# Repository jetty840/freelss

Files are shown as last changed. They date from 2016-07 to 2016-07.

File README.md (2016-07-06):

#FreeLSS

FreeLSS is a laser scanning program for the Raspberry Pi. It allows a Raspberry Pi to function as the core to a complete turn table laser scanning system.

###THIS FORK

This fork adds Neopixel ring support to freelss.  It includes the circuit/board design for a small mainly SMD shield to handle Neopixels / lasers and steppers.

The advantage of the Neopixel ring is adjustable color and brightness for illumination of the object and reporting of the ip address at startup (useful in DHCP configs).

If you are not usng Neopixels, you can still use the board and omit a few components if you require a small form factor, or use a different board.

Additionally, custom PWM (White) lighting can be setup such that the model and lasers can have different ambient lighting.

###COMPILE

These instructions assume you are running the latest version of Raspbian.  Other distros will likely require changes.

First, update the firmware to the latest version and reboot.
```
$ sudo apt-get update
$ sudo apt-get upgrade
```

Install the dependencies that are managed by the package manager.
```
$ sudo apt-get install libpng-dev libjpeg-dev cmake vlc git-core gcc build-essential unzip sqlite3 libsqlite3-dev libmicrohttpd-dev libcurl4-openssl-dev libiw-dev libssl-dev
```

Download and install wiringPi
```
$ git clone git://git.drogon.net/wiringPi
$ cd wiringPi
$ ./build
$ cd ..
```

Disable the soundcard on the Pi (interferes with Neopixels):
Reference: http://www.instructables.com/id/Disable-the-Built-in-Sound-Card-of-Raspberry-Pi/
```
$ cd /etc/modprobe.d
$ sudo vi alsa-blacklist.conf
Add the following line:
  blacklist snd_bcm2835
Save
$ sudo reboot

After reboot:
$ aplay -l
  Should say "No soundcards found"

```

Download and install rpi_ws821x
Reference: https://learn.adafruit.com/neopixels-on-raspberry-pi/software
```
$ sudo apt-get install build-essential python-dev git scone swig
$ git clone https://github.com/jgarff/rpi_ws281x.git
$ cd rpi_ws281x
$ scons
$ sudo ./test
(Neopixels will go through color cycling, press CTRL-C when done)
$ cd ..
```

Download and build FreeLSS
```
$ git clone https://github.com/jetty840/freelss
$ cd freelss/src
$ make
```
###Running FreeLSS
FreeLSS must be ran as root (or another user with access to the hardware pins).  The interface for FreeLSS is web based and by default runs on port 80.  When running, access it by navigating to http://localhost/ from the Raspberry Pi itself. Or access it from another machine on the network by the Raspberry Pi's IP or hostname.  For Example: http://raspberrypi/

The following command starts FreeLSS.
```
$ sudo ./freelss
```

The following command automatically starts FreeLSS everytime the Raspberry Pi is powered on.
```
$ make startup
```

###Pin Configuraton
For FreeLSS running with the provided schematic/PCB in this fork, configuration for this board is as follows:
```
Right Laser Pin: 4
Left Laser Pin: 0
Laser On Value: 1
Motor Enable Pin: 5
Motor Step Pin: 2
Motor Step Delay: 5000
Motor Direction Pin: 3
Motor Response Delay: 2
Enable Lighting: Checked
Light Type: WS281x
Lighting Pin: 18
```

###Building the board
Populate R4/R6 OR D1/D2, depending on your laser diodes.  If it's 5V and can control it's own current, then populate R4/R6 with a zero ohm resistor.  Otherwise to get the correct voltage for the laser diode, D1/D2 can be used as a Diode drop, and the trace from the middle of the diode pair to +5V can be cut and used as 2 diode drops if required.  Alternative R4/R6 can be used to limit voltage/current less accurately.

For the PI header, decide if you want to use it as a shield (use a PI Stacking Header), or wire 0.1" pin headers if you wish to cable it out (verify pin 1 = pin 1 if you're using IDC headers and a cable).

Adafruit 12 LED Neopixel ring recommended (720ma).  Be careful of current here, the Pi needs to be able to handle it, or supply power using a different method.

2A Minimum 5V PSU required.

DISCLAIMER: By using this design and/or fork, you acknowledge that you do so entirely at your own risk and that you will not hold the author liable under any cicrumstances.

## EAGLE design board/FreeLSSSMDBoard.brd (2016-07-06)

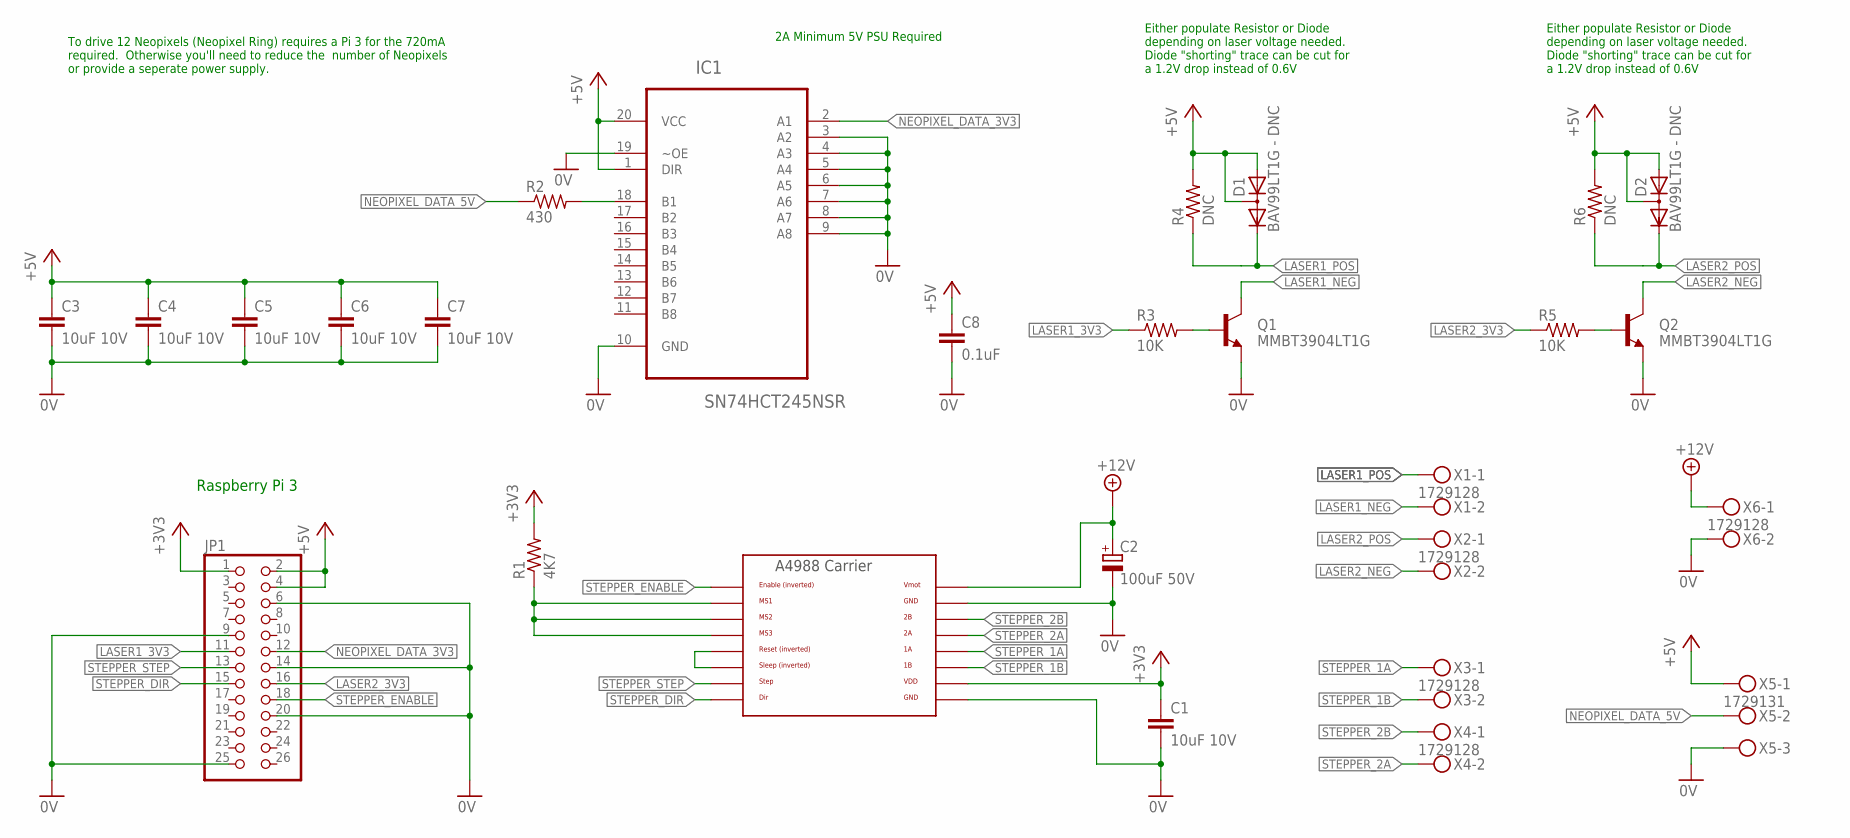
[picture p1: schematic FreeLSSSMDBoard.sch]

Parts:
C1, C3, C4, C5, C6, C7: 10uF 10V; C0603K
C2: 100uF 50V; E3,5-8
C8: 0.1uF; C0603K
D1, D2: BAV99LT1G - DNC; SOT23
IC1: SN74HCT245NSR; SOP-20
JP1: PINHD-2X13; 2X13
Q1, Q2: MMBT3904LT1G; SOT23-BEC
R1: 4K7; R0603
R2: 430; R0603
R3, R5: 10K; R0603
R4, R6: DNC; R0603
U$1: A4988BREAKOUT
X1, X2, X3, X4, X6: 1729128; MKDSN1,5/2-5,08
X5: 1729131; MKDSN1,5/3-5,08

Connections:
0V: C1.2, C2.-, C3.2, C4.2, C5.2, C6.2, C7.2, C8.2, IC1.3 (A2), IC1.4 (A3), IC1.5 (A4), IC1.6 (A5), IC1.7 (A6), IC1.8 (A7), IC1.9 (A8), IC1.10 (GND), IC1.19 (~OE), JP1.6, JP1.9, JP1.14, JP1.20, JP1.25, Q1.E, Q2.E, U$1.GND, U$1.GND@0 (GND), X5.3, X6.2
+3V3: C1.1, JP1.1, R1.2, U$1.VDD
+5V: C3.1, C4.1, C5.1, C6.1, C7.1, C8.1, D1.1 (A), D1.3 (AC), D2.1 (A), D2.3 (AC), IC1.1 (DIR), IC1.20 (VCC), JP1.2, JP1.4, R4.2, R6.2, X5.1
+12V: C2.+, U$1.VMOT, X6.1
LASER1_3V3: JP1.11, R3.1
LASER1_NEG: Q1.C, X1.2
LASER1_POS: D1.2 (C), R4.1, X1.1
LASER2_3V3: JP1.16, R5.1
LASER2_NEG: Q2.C, X2.2
LASER2_POS: D2.2 (C), R6.1, X2.1
unnamed: U$1.RST, U$1.SLP (SLEEP)
unnamed: R1.1, U$1.MS1, U$1.MS2, U$1.MS3
unnamed: IC1.18 (B1), R2.2
unnamed: Q1.B, R3.2
unnamed: Q2.B, R5.2
NEOPIXEL_DATA_3V3: IC1.2 (A1), JP1.12
NEOPIXEL_DATA_5V: R2.1, X5.2
STEPPER_1A: U$1.1A, X3.1
STEPPER_1B: U$1.1B, X3.2
STEPPER_2A: U$1.2A, X4.2
STEPPER_2B: U$1.2B, X4.1
STEPPER_DIR: JP1.15, U$1.DIR
STEPPER_ENABLE: JP1.18, U$1.EN
STEPPER_STEP: JP1.13, U$1.STEP

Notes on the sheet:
Raspberry Pi 3
Either populate Resistor or Diode depending on laser voltage needed. Diode "shorting" trace can be cut for a 1.2V drop instead of 0.6V
To drive 12 Neopixels (Neopixel Ring) requires a Pi 3 for the 720mA required. Otherwise you'll need to reduce the number of Neopixels or provide a seperate power supply.
2A Minimum 5V PSU Required

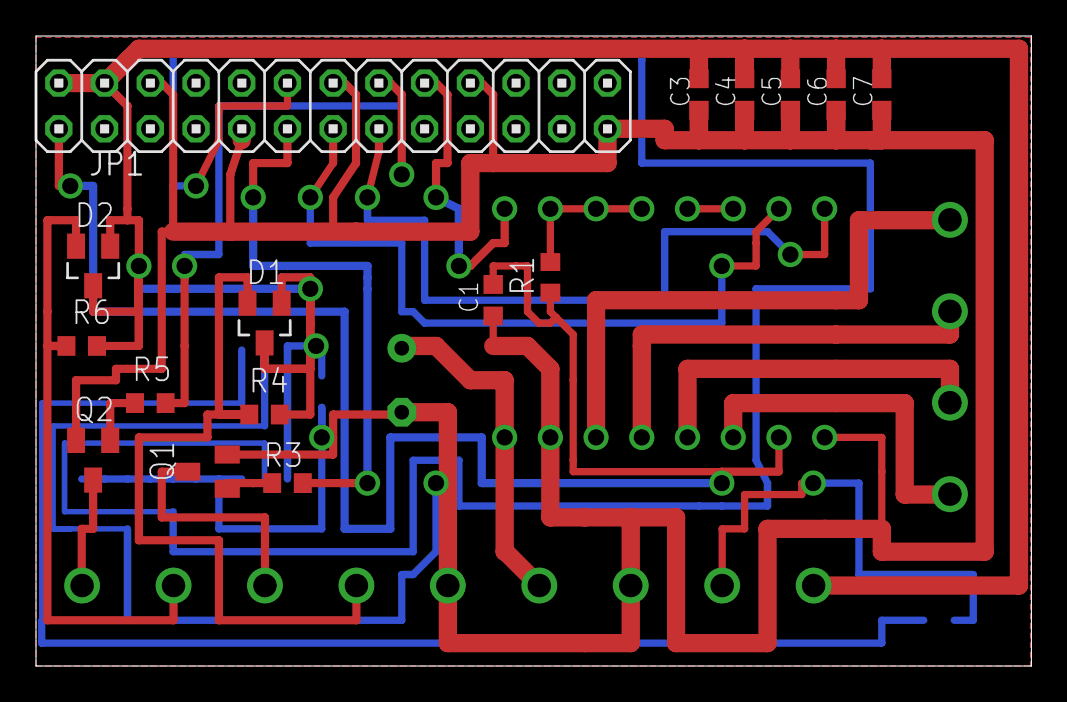
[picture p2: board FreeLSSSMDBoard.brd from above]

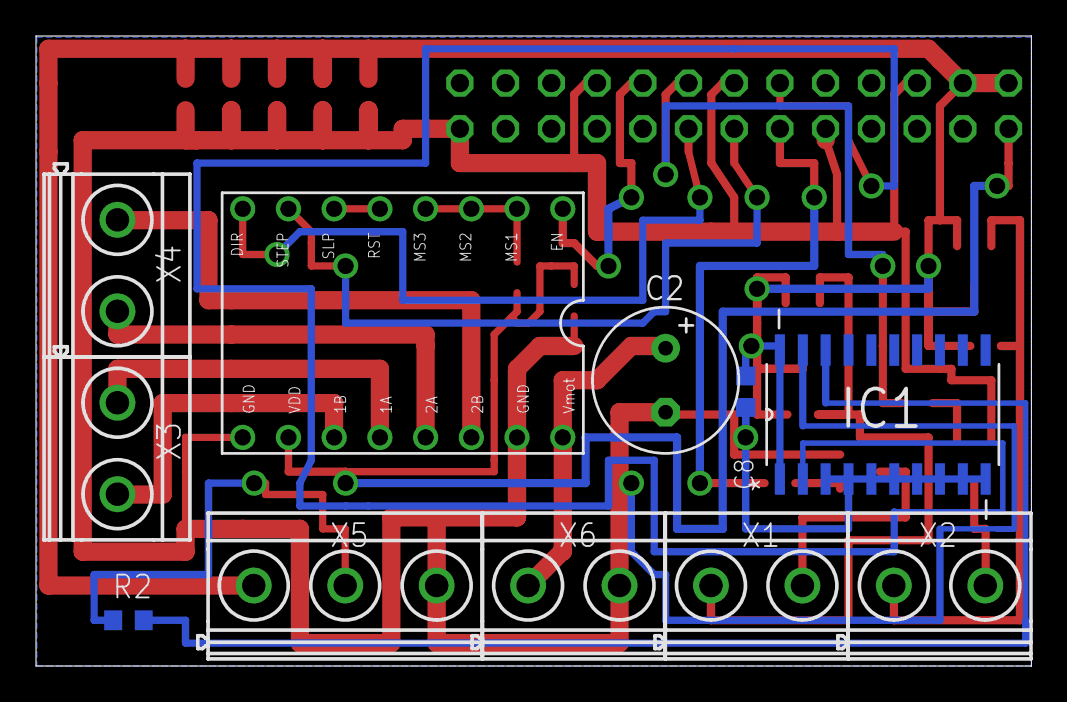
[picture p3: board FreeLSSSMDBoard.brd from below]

Board: 2 copper layers, 55.3 x 35.0 mm, 27 parts (11 on the bottom side), 24 nets.

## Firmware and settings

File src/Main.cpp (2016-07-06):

/*
 ****************************************************************************
 *  Copyright (c) 2014 Uriah Liggett <freelaserscanner@gmail.com>           *
 *	This file is part of FreeLSS.                                           *
 *                                                                          *
 *  FreeLSS is free software: you can redistribute it and/or modify         *
 *  it under the terms of the GNU General Public License as published by    *
 *  the Free Software Foundation, either version 3 of the License, or       *
 *  (at your option) any later version.                                     *
 *                                                                          *
 *  FreeLSS is distributed in the hope that it will be useful,              *
 *  but WITHOUT ANY WARRANTY; without even the implied warranty of          *
 *  MERCHANTABILITY or FITNESS FOR A PARTICULAR PURPOSE.  See the           *
 *  GNU General Public License for more details.                            *
 *                                                                          *
 *   You should have received a copy of the GNU General Public License      *
 *   along with FreeLSS.  If not, see <http://www.gnu.org/licenses/>.       *
 ****************************************************************************
*/

#include "Main.h"
#include "Camera.h"
#include "Scanner.h"
#include "A4988TurnTable.h"
#include "RelayLaser.h"
#include "PresetManager.h"
#include "HttpServer.h"
#include "PresetManager.h"
#include "PropertyReaderWriter.h"
#include "Setup.h"
#include "UpdateManager.h"
#include "Lighting.h"
#include "WifiConfig.h"
#include <curl/curl.h>
#include <algorithm>

static bool SortRecordByRow(const freelss::DataPoint& a, const freelss::DataPoint& b)
{
	return a.pixel.y < b.pixel.y;
}

std::string GetPropertiesFile()
{
	// Get the users home directory
	char * home = getenv("HOME");
	if (home == NULL)
	{
		std::cerr << "Could not detect the user's home directory";
		return "";
	}

	return home + std::string("/.freelss.properties");
}

/** Initializes and destroys libcurl */
struct InitCurl
{
	InitCurl()
	{
		curl_global_init(CURL_GLOBAL_ALL);
	}

	~InitCurl()
	{
		curl_global_cleanup();
	}
};

/** Initializes and destroys the singletons */
struct InitSingletons
{
	InitSingletons()
	{
		freelss::PresetManager::get();
		freelss::A4988TurnTable::initialize();
		freelss::RelayLaser::initialize();
		freelss::UpdateManager::get();
		freelss::Setup::get();
		freelss::Lighting::get();
		freelss::WifiConfig::get();
		freelss::HttpServer::get();
	}

	~InitSingletons()
	{
		freelss::HttpServer::release();
		freelss::Laser::release();
		freelss::Camera::release();
		freelss::TurnTable::release();
		freelss::UpdateManager::release();
		freelss::PresetManager::release();
		freelss::Lighting::release();
		freelss::WifiConfig::release();
		freelss::Setup::release();
	}
};

/** Initializes and destroys the Raspberry Pi subsystem */
struct InitBcmHost
{
	InitBcmHost()
	{
		bcm_host_init();
	}

	~InitBcmHost()
	{
		bcm_host_deinit();
	}
};

int main(int argc, char **argv)
{
	int retVal = 0;

	pid_t pid = fork();
	if (pid < 0)
	{
		std::cerr << "Error forking process!!!" << std::endl;
		return 1;
	}
	else if (pid != 0)
	{
		return 0;
	}

	// Initialize the Raspberry Pi hardware
	InitBcmHost bcmHost;

	try
	{
		// Setup wiring pi
		wiringPiSetup();

		// Initialize Curl
		InitCurl curl();

		// Load the properties
		freelss::LoadProperties();

		// Initialize the singletons
		InitSingletons singletons;

		freelss::WifiConfig::get()->displayNetworkIpAddress();

		int port = freelss::Setup::get()->httpPort;

		std::cout << "Running on port " << port << "..." << std::endl;
		freelss::HttpServer::get()->start(port);

		while (true)
		{
			freelss::Thread::usleep(500000);  // Sleep 500ms
		}
	}
	catch (freelss::Exception& ex)
	{
		std::cerr << "Exception: " << ex << std::endl;
		retVal = -1;
	}
	catch (std::exception& ex)
	{
		std::cerr << "Exception: " << ex.what() << std::endl;
		retVal = -1;
	}
	catch (...)
	{
		std::cerr << "Unknown Exception Occurred" << std::endl;
		retVal = -1;
	}

	return retVal;
}

namespace freelss
{

const std::string SCAN_OUTPUT_DIR = "/scans";
const std::string DEBUG_OUTPUT_DIR = "/debug";
const std::string PROPERTIES_FILE = GetPropertiesFile();

time_t ScanResult::getScanDate() const
{
	if (files.empty())
	{
		return 0;
	}

	return files.front().creationTime;
}

bool DataPoint::readNextFrame(std::vector<DataPoint>& out, const std::vector<DataPoint>& results, size_t & resultIndex)
{
	out.clear();

	if (resultIndex >= results.size() || results.empty())
	{
		return false;
	}

	int pseudoStep = results[resultIndex].pseudoFrame;
	while (pseudoStep == results[resultIndex].pseudoFrame && resultIndex < results.size())
	{
		out.push_back(results[resultIndex]);
		resultIndex++;
	}

	return true;
}

bool DataPoint::readNextFrame(const std::vector<DataPoint>& results, size_t & resultIndex)
{
	if (resultIndex >= results.size() || results.empty())
	{
		return false;
	}

	int pseudoStep = results[resultIndex].pseudoFrame;
	while (pseudoStep == results[resultIndex].pseudoFrame && resultIndex < results.size())
	{
		resultIndex++;
	}

	return true;
}

void DataPoint::computeAverage(const std::vector<DataPoint>& bin, DataPoint& out)
{
	out = bin.front();

	real32 invSize = 1.0f / bin.size();

	real32 rotation = 0;
	real32 pixelLocationX = 0;
	real32 pixelLocationY = 0;
	real32 ptX = 0;
	real32 ptY = 0;
	real32 ptZ = 0;
	real32 ptR = 0;
	real32 ptG = 0;
	real32 ptB = 0;

	for (size_t iBin = 0; iBin < bin.size(); iBin++)
	{
		const DataPoint& br = bin[iBin];

		rotation += invSize * br.rotation;
		pixelLocationX += invSize * br.pixel.x;
		pixelLocationY += invSize * br.pixel.y;
		ptX += invSize * br.point.x;
		ptY += invSize * br.point.y;
		ptZ += invSize * br.point.z;
		ptR += invSize * br.point.r;
		ptG += invSize * br.point.g;
		ptB += invSize * br.point.b;
	}

	out.rotation = rotation;
	out.pixel.x = pixelLocationX;  // TODO: We should probably round these values
	out.pixel.y = pixelLocationY;
	out.point.x = ptX;
	out.point.y = ptY;
	out.point.z = ptZ;
	out.point.r = ptR;
	out.point.g = ptG;
	out.point.b = ptB;
}

void DataPoint::lowpassFilter(std::vector<DataPoint>& output, std::vector<DataPoint>& frame, unsigned maxNumRows, unsigned numRowBins)
{
	// Sanity check
	if (frame.empty())
	{
		return;
	}

	// No binning can occur, so copy
	if (numRowBins >= maxNumRows)
	{
		output.insert(output.end(), frame.begin(), frame.end());
		return;
	}

	// Sort by image row
	std::sort(frame.begin(), frame.end(), SortRecordByRow);

	unsigned binSize = maxNumRows / numRowBins;

	// Holds the current contents of the bin
	std::vector<DataPoint> bin;
	unsigned nextBinY = frame.front().pixel.y + binSize;

	// unsigned bin = frame.front().pixel.y / numRowBins;
	for (size_t iFr = 0; iFr < frame.size(); iFr++)
	{
		DataPoint& record = frame[iFr];

		if (record.pixel.y < nextBinY)
		{
			bin.push_back(record);
		}
		else
		{
			// Average the bin results and add it to the output
			if (!bin.empty())
			{
				DataPoint out;
				computeAverage(bin, out);

				output.push_back(out);
				bin.clear();
			}

			nextBinY = record.pixel.y + binSize;
			bin.push_back(record);
		}
	}

	// Process any results still left in the bin
	if (!bin.empty())
	{
		DataPoint out;
		computeAverage(bin, out);

		output.push_back(out);
		bin.clear();
	}
}


void LoadProperties()
{
	PropertyReaderWriter reader;

	std::vector<Property> properties;

	// Read the presets from the file
	if (access(PROPERTIES_FILE.c_str(), F_OK) != -1)
	{
		properties = reader.readProperties(PROPERTIES_FILE);
	}

	PresetManager * presetMgr = PresetManager::get();

	// Read the presets
	presetMgr->decodeProperties(properties);

	// Create the default Preset object if there are no presets
	if (presetMgr->getPresets().empty())
	{
		Preset defaultPreset;
		defaultPreset.name = "Default";

		defaultPreset.id = presetMgr->addPreset(defaultPreset);
		presetMgr->setActivePreset(defaultPreset.id);
	}

	// Load the hardware setup information
	Setup::get()->decodeProperties(properties);
}

void SaveProperties()
{
	// Encode the info as Property objects
	std::vector<Property> properties;
	PresetManager::get()->encodeProperties(properties);
	Setup::get()->encodeProperties(properties);

	PropertyReaderWriter writer;
	writer.writeProperties(properties, PROPERTIES_FILE);
}

real ConvertUnitOfLength(real value, UnitOfLength srcUnits, UnitOfLength dstUnits)
{
	// Shortcut
	if (srcUnits == dstUnits)
	{
		return value;
	}

	//
	// Convert to millimeters
	//
	real mmValue;
	if (srcUnits == UL_MILLIMETERS)
	{
		mmValue = value;
	}
	else if (srcUnits == UL_CENTIMETERS)
	{
		mmValue = value * 10.0;
	}
	else if (srcUnits == UL_INCHES )
	{
		mmValue = value * 25.4;
	}
	else
	{
		throw Exception("Unsupported Unit of Length");
	}

	//
	// Convert to destination units
	//
	real out;
	if (dstUnits == UL_MILLIMETERS)
	{
		out = mmValue;
	}
	else if (dstUnits == UL_CENTIMETERS)
	{
		out = mmValue / 10.0;
	}
	else if (dstUnits == UL_INCHES)
	{
		out = mmValue / 25.4;
	}
	else
	{
		throw Exception("Unsupported Unit of Length");
	}

	return out;
}

double GetTimeInSeconds()
{
	struct timeval tv;
	if (gettimeofday(&tv, NULL) != 0)
	{
		std::cerr << "Error calling gettimeofday()" << std::endl;
	}

	double sec = tv.tv_sec;

	if (tv.tv_usec != 0)
	{
		sec += tv.tv_usec / 1000000.0;  // US to SEC
	}

	return sec;
}

int GetFreeSpaceMb()
{
	int freeSpaceMb = 0;
	struct statvfs fileSystemInfo;
	if (statvfs(SCAN_OUTPUT_DIR.c_str(), &fileSystemInfo) == 0)
	{
		real freeSpaceBytes = (real)fileSystemInfo.f_bsize * (real)fileSystemInfo.f_bfree;
		freeSpaceMb = (int)(freeSpaceBytes / 1024.0f / 1024.0f);
	}

	return freeSpaceMb;
}

std::string ToString(UnitOfLength unit)
{
	std::string out;

	switch(unit)
	{
	case UL_MILLIMETERS:
		out = "mm";
		break;

	case UL_CENTIMETERS:
		out = "cm";
		break;

	case UL_INCHES:
		out = "in";
		break;

	default:
		throw Exception("Unsupported unit of measure");
	}

	return out;
}

std::string ToHexString(unsigned char * data, size_t dataLength)
{
	std::stringstream sstr;
	for (size_t iDat = 0; iDat < dataLength; iDat++)
	{
		sstr << std::setbase(16) << (unsigned) data[iDat];
	}

	return sstr.str();
}

std::string ToString(real value)
{
	std::stringstream sstr;
	sstr << value;

	return sstr.str();
}

std::string ToString(int value)
{
	std::stringstream sstr;
	sstr << value;

	return sstr.str();
}

std::string ToString(bool value)
{
	return value ? "1" : "0";
}

std::string ToString(uint32_t value)
{
	std::stringstream sstr;
	sstr << std::setfill('0') << std::setw(6) << std::hex << value;

	return sstr.str();
}

real ToReal(const std::string& str)
{
	return atof(str.c_str());
}

int ToInt(const std::string& str)
{
	return atoi(str.c_str());
}

uint32_t ToUInt32(const std::string& str)
{
	return (uint32_t)strtoul(str.c_str(), NULL, 16);
}

bool ToBool(const std::string& str)
{
	return str == "1" || str == "true" || str == "on";
}

bool EndsWith(const std::string& str, const std::string& ending)
{
	if (str.length() >= ending.length())
	{
		return (0 == str.compare (str.length() - ending.length(), ending.length(), ending));
	}

	return false;
}

void HtmlEncode(std::string& str)
{
    std::string buffer;
    buffer.reserve(str.size());
    for(size_t iPos = 0; iPos != str.size(); ++iPos)
    {
        switch(str[iPos])
        {
            case '\"': buffer.append("&quot;");      break;
            case '\'': buffer.append("&apos;");      break;
            case '<':  buffer.append("&lt;");        break;
            case '>':  buffer.append("&gt;");        break;
            case '.':  buffer.append("&#46;");       break;
            case '=':  buffer.append("&#61;");       break;
            default:   buffer.append(&str[iPos], 1); break;
        }
    }

    str.swap(buffer);
}

void ExitProgram()
{
	//G_running = false;
}

} // ns scanner

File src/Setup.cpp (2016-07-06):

/*
 ****************************************************************************
 *  Copyright (c) 2015 Uriah Liggett <freelaserscanner@gmail.com>           *
 *	This file is part of FreeLSS.                                           *
 *                                                                          *
 *  FreeLSS is free software: you can redistribute it and/or modify         *
 *  it under the terms of the GNU General Public License as published by    *
 *  the Free Software Foundation, either version 3 of the License, or       *
 *  (at your option) any later version.                                     *
 *                                                                          *
 *  FreeLSS is distributed in the hope that it will be useful,              *
 *  but WITHOUT ANY WARRANTY; without even the implied warranty of          *
 *  MERCHANTABILITY or FITNESS FOR A PARTICULAR PURPOSE.  See the           *
 *  GNU General Public License for more details.                            *
 *                                                                          *
 *   You should have received a copy of the GNU General Public License      *
 *   along with FreeLSS.  If not, see <http://www.gnu.org/licenses/>.       *
 ****************************************************************************
*/
#include "Main.h"
#include "Setup.h"

namespace freelss
{

Setup * Setup::m_instance = NULL;

Setup * Setup::get()
{
	if (Setup::m_instance == NULL)
	{
		Setup::m_instance = new Setup();
	}

	return Setup::m_instance;
}

void Setup::release()
{
	delete Setup::m_instance;
	Setup::m_instance = NULL;
}

Setup::Setup() :
	cameraLocation(),
	leftLaserLocation(),
	rightLaserLocation(),
	rightLaserPin(5),
	leftLaserPin(4),
	motorEnablePin(0),
	motorStepPin(7),
	motorDirPin(1),
	motorDirPinValue(0),
	laserOnValue(1),
	stepsPerRevolution(3200),
	motorResponseDelay(2),
	motorStepDelay(5000),
	httpPort(80),
	serialNumber(""),
	unitOfLength(UL_INCHES),
	haveLaserPlaneNormals(false),
	enableLighting(false),
	lightingType(LT_PWM),
	lightingPin(3),
	lightingIlluminationRGB(0xFFFFFF),
	lightingLaserRGB(0x222222),
	lightingNetworkIndication(LN_OFF),
	lightingNetworkInterface("eth0"),
	enableAuthentication(false),
	passwordHash("")
{
	cameraLocation.x = 0;
	cameraLocation.y = 82.55;
	cameraLocation.z = 260.35;

	leftLaserLocation.x = -125.73;
	leftLaserLocation.y = 82.55;
	leftLaserLocation.z = 260.35;

	rightLaserLocation.x = 125.73;
	rightLaserLocation.y = 82.55;
	rightLaserLocation.z = 260.35;

	leftLaserPlaneNormal.x = 0;
	leftLaserPlaneNormal.y = 0;
	leftLaserPlaneNormal.z = 0;

	rightLaserPlaneNormal.x = 0;
	rightLaserPlaneNormal.y = 0;
	rightLaserPlaneNormal.z = 0;
}


void Setup::encodeProperties(std::vector<Property>& properties)
{
	properties.push_back(Property("setup.cameraLocation.x", ToString(cameraLocation.x)));
	properties.push_back(Property("setup.cameraLocation.y", ToString(cameraLocation.y)));
	properties.push_back(Property("setup.cameraLocation.z", ToString(cameraLocation.z)));

	properties.push_back(Property("setup.leftLaserLocation.x", ToString(leftLaserLocation.x)));
	properties.push_back(Property("setup.leftLaserLocation.y", ToString(leftLaserLocation.y)));
	properties.push_back(Property("setup.leftLaserLocation.z", ToString(leftLaserLocation.z)));

	properties.push_back(Property("setup.rightLaserLocation.x", ToString(rightLaserLocation.x)));
	properties.push_back(Property("setup.rightLaserLocation.y", ToString(rightLaserLocation.y)));
	properties.push_back(Property("setup.rightLaserLocation.z", ToString(rightLaserLocation.z)));

	properties.push_back(Property("setup.rightLaserPin", ToString(rightLaserPin)));
	properties.push_back(Property("setup.leftLaserPin", ToString(leftLaserPin)));
	properties.push_back(Property("setup.motorEnablePin", ToString(motorEnablePin)));
	properties.push_back(Property("setup.motorStepPin", ToString(motorStepPin)));
	properties.push_back(Property("setup.motorDirPin", ToString(motorDirPin)));
	properties.push_back(Property("setup.motorDirPinValue", ToString(motorDirPinValue)));
	properties.push_back(Property("setup.laserOnValue", ToString(laserOnValue)));
	properties.push_back(Property("setup.stepsPerRevolution", ToString(stepsPerRevolution)));
	properties.push_back(Property("setup.motorResponseDelay", ToString(motorResponseDelay)));
	properties.push_back(Property("setup.motorStepDelay", ToString(motorStepDelay)));
	properties.push_back(Property("setup.httpPort", ToString(httpPort)));
	properties.push_back(Property("setup.serialNumber", serialNumber));
	properties.push_back(Property("setup.unitOfLength", ToString((int)unitOfLength)));
	properties.push_back(Property("setup.haveLaserPlaneNormals", ToString(haveLaserPlaneNormals)));
	properties.push_back(Property("setup.enableLighting", ToString(enableLighting)));
	properties.push_back(Property("setup.lightingType", ToString((int)lightingType)));
	properties.push_back(Property("setup.lightingPin", ToString(lightingPin)));
	properties.push_back(Property("setup.lightingIlluminationRGB", ToString(lightingIlluminationRGB)));
	properties.push_back(Property("setup.lightingLaserRGB", ToString(lightingLaserRGB)));
	properties.push_back(Property("setup.lightingNetworkIndication", ToString((int)lightingNetworkIndication)));
	properties.push_back(Property("setup.lightingNetworkInterface", lightingNetworkInterface));
	properties.push_back(Property("setup.enableAuthentication", ToString(enableAuthentication)));
	properties.push_back(Property("setup.passwordHash", passwordHash));


	if (haveLaserPlaneNormals)
	{
		properties.push_back(Property("setup.leftLaserPlaneNormal.x", ToString(leftLaserPlaneNormal.x)));
		properties.push_back(Property("setup.leftLaserPlaneNormal.y", ToString(leftLaserPlaneNormal.y)));
		properties.push_back(Property("setup.leftLaserPlaneNormal.z", ToString(leftLaserPlaneNormal.z)));

		properties.push_back(Property("setup.rightLaserPlaneNormal.x", ToString(rightLaserPlaneNormal.x)));
		properties.push_back(Property("setup.rightLaserPlaneNormal.y", ToString(rightLaserPlaneNormal.y)));
		properties.push_back(Property("setup.rightLaserPlaneNormal.z", ToString(rightLaserPlaneNormal.z)));

		properties.push_back(Property("setup.leftLaserCalibrationTop.x", ToString(leftLaserCalibrationTop.x)));
		properties.push_back(Property("setup.leftLaserCalibrationTop.y", ToString(leftLaserCalibrationTop.y)));

		properties.push_back(Property("setup.leftLaserCalibrationBottom.x", ToString(leftLaserCalibrationBottom.x)));
		properties.push_back(Property("setup.leftLaserCalibrationBottom.y", ToString(leftLaserCalibrationBottom.y)));

		properties.push_back(Property("setup.rightLaserCalibrationTop.x", ToString(rightLaserCalibrationTop.x)));
		properties.push_back(Property("setup.rightLaserCalibrationTop.y", ToString(rightLaserCalibrationTop.y)));
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

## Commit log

2016-07-06 Added ip reporting, tested working on Pi 3 with 12 Pixel Neopixel Ring and included board.
2016-07-06 Added boards
    [FreeLSSSMDBoard.brd, FreeLSSSMDBoard.sch]
